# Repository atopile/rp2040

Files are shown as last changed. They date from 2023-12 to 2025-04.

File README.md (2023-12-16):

# RP2040

## Installation
Run in the terminal:

```ato install rp2040```

Add to your ato project:

```import RP2040Kit from "rp2040/rp2040.ato"```

[LINK](https://gitlab.atopile.io/packages/RP2040) to the repo.

## Overview

This package should include all the basics needed to layout an RP2040 microcontroller.

## Features

- **Power Interface:** 3.3v voltage input
- **SPI Interface**
- **I2C Interface** Inter-Integrated Circuit interface for connecting low-speed peripherals.
- **USB 2.0 Interface** Handy to program the rp2040. Hook this up to an usb-c. There is a usb-c in a module as well.
- **GPIO Pins:** General Purpose Input/Output pins for digital input/output functionality.
- **Analog Inputs:** Four analog inputs (A0-A3) for reading analog signals.

## Getting Started

1. **Powering the Module:** Requires a 3.3V supply connected to the power interface.
2. **Connecting Interfaces:** Utilize SPI, I2C, and USB interfaces as per your project requirements.
3. **Utilizing GPIO and Analog Inputs:** Connect your sensors or peripherals to the GPIO or analog inputs as needed.
4. **Programming:** Program the module using your preferred development environment compatible with the RP2040.

## Example Layout

![Example Layout](docs/layout-example.png)

### Layout notes
- Caps should be close to the micro on the 3V3 an 1V1 rails
- 12MHz crystal should be close to micro
- USB series resistors should be close to micro
- Maybe just put everything close to the micro...

## Documentation & Resources

- [Official RP2040 Datasheet](https://datasheets.raspberrypi.com/rp2040/hardware-design-with-rp2040.pdf)

Here is roughly what's going on in the module:

![whats-going-on-in-the-module](docs/rp2040Kit.png)

What you have to deal with:
![courtesy_of_john_mcmaster](https://siliconpr0n.org/map/raspberry-pi/rp2-b0/single/raspberry-pi_rp2-b0_mcmaster_s1-9_vc60x.jpg)
*Courstesy of John Mcmaster*

## Contributing

Contribute to this package using pull requests.

## License

This RP2040 module documentation is provided under the [MIT License](https://opensource.org/license/mit/).

## Contact

For further inquiries or support, please contact us at [narayan@atopile.io](mailto:narayan@atopile.io).

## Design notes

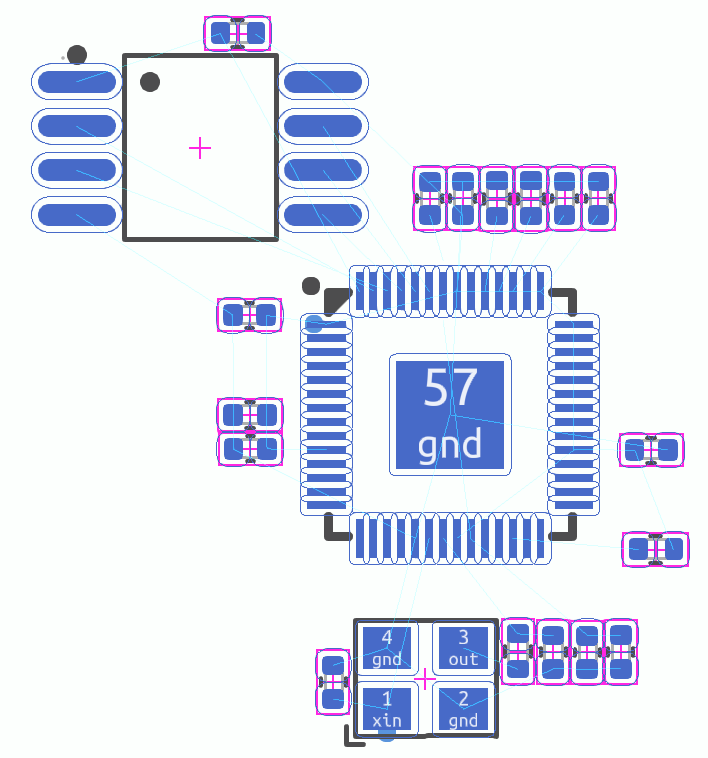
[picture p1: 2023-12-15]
docs/layout-example.png

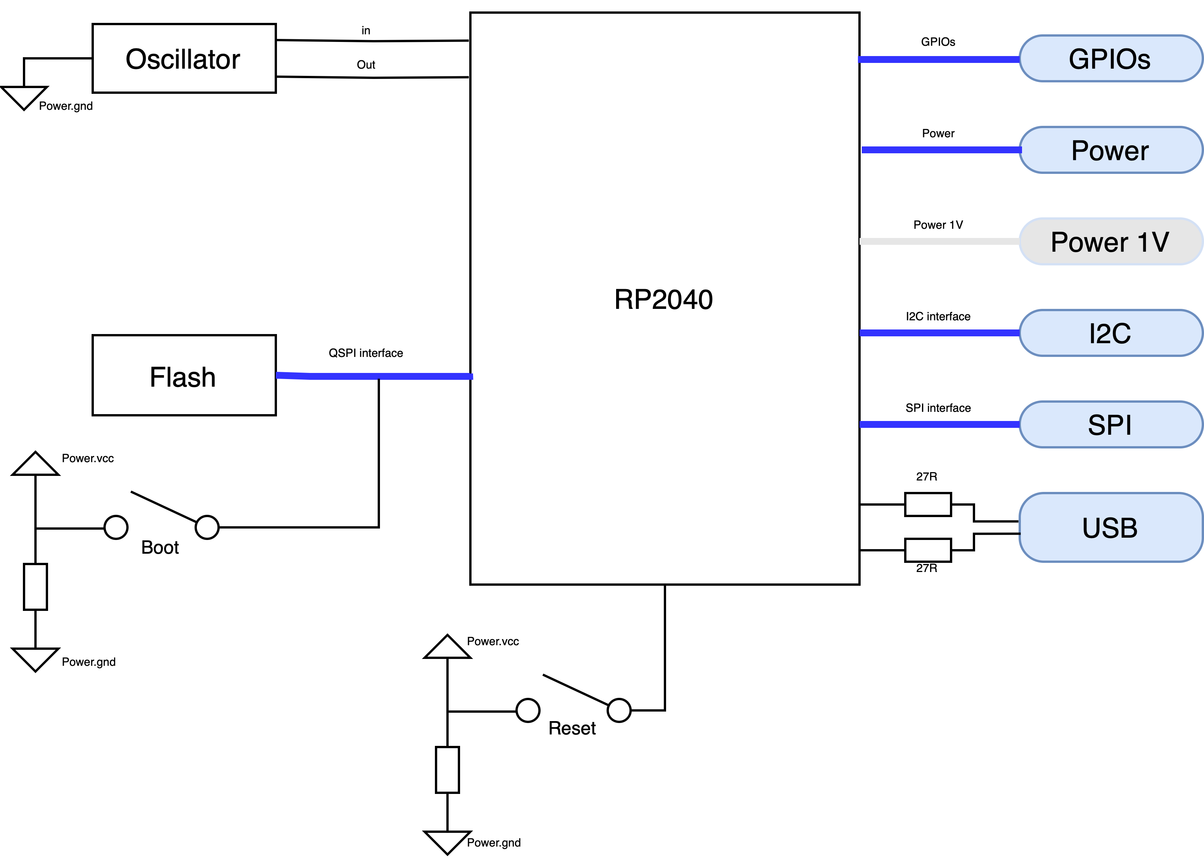
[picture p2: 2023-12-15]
docs/rp2040Kit.png

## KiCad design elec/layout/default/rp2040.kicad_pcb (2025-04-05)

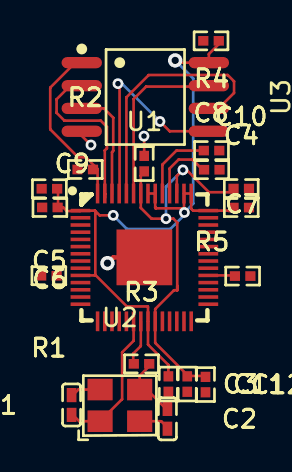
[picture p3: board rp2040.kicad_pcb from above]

Board: 2 copper layers, 20 parts (0 on the bottom side), 15 nets.

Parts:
C1, C2: 22pF ±5% 50V C0G; C0402-b3ef17
C3, C4, C5, C6, C7, C9, C10, C11: 100nF ±10% 50V X7R; R0402
C8, C12: 1µF ±10% 25V X5R; R0402
R1, R2: 10kΩ ±1% 62.5mW; R0402-56259e
R3: 1kΩ ±1% 62.5mW; R0402-56259e
R4, R5: 27Ω ±1% 62.5mW; R0402-56259e
U1: LQFN-56_L7.0-W7.0-P0.4-EP
U2: OSC-SMD_4P-L3.2-W2.5-BL
U3: SOIC-8_L5.3-W5.3-P1.27-LS8.0-BL

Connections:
cs-1: R2.2, U1.56, U3.1
gnd: C1.2, C2.2, C3.2, C4.2, C5.2, C6.2, C7.2, C8.2, C9.2, C10.2, C11.2, C12.2, U1.19, U1.57, U2.2, U2.4, U3.4
hv: C3.1, C4.1, C5.1, C6.1, C7.1, C8.1, R1.1, R2.1, U1.1, U1.10, U1.22, U1.33, U1.42, U1.43, U1.44, U1.48, U1.49, U3.8
hv-1: C9.1, C10.1, C11.1, C12.1, U1.23, U1.45, U1.50
input: C1.1, U1.20, U2.1
io0: U1.53, U3.5
io1: U1.55, U3.2
io2: U1.54, U3.3
io3: U1.51, U3.7
osc-out: C2.1, R3.2, U2.3
out: R1.2, U1.26
sck-1: U1.52, U3.6
usb_dm: R5.2, U1.46
usb_dp: R4.1, U1.47
xout: R3.1, U1.21

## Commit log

2023-12-10 Install footprints here
2023-12-10 Add USB-C connector to the kit
2023-12-10 Remove boot pulldown resistor
2023-12-11 fix footprint
2023-12-14 updating footprints to 0402
2024-02-13 added uart interface
2024-02-13 added layout
    [rp2040.kicad_pcb, rp2040.kicad_sch]
2024-02-14 fix the layout
    [rp2040.kicad_pcb]
2024-02-14 added new spi interface
2024-02-14 swapped button for generic pullup button from generics
2024-02-17 Refactor power management
    Use inheritance to control power management for the
    RP2040 kit.
    Add an example for 3v3 power from USB using 5v transformer
2024-02-19 switch to one line import
2024-02-20 refactored kid into core, split USB and 3v3 power into two subclasses
2024-03-01 fixing values for usb resistors
2024-03-01 fixing usb resistors
2024-03-10 fix USB resistors
    [rp2040.kicad_pcb]
2024-03-10 Fix ADC power issue
    [rp2040.kicad_pcb]
2024-03-19 fixing name conflict for power net
2024-10-28 Remove xmas crud
    [rp2040.kicad_pcb]
2024-12-31 Update layout for v0.3
    [rp2040.kicad_pcb]
2025-01-02 Update after fixing net naming collision
    [rp2040.kicad_pcb]
2025-01-14 Add new layout properties to PCB
    [rp2040.kicad_pcb]
2025-01-16 New properties in layout
    [rp2040.kicad_pcb]
2025-04-05 update to kicad 9
    [rp2040.kicad_pcb]
2025-04-05 build with latest
    [rp2040.kicad_pcb]
